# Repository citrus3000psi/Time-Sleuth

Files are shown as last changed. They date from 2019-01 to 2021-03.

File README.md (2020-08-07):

# Time Sleuth

A cheap and easy to build HDMI lag tester.  Through hole components were chosen to aid in assembly.  Resistors and Caps are still surface mount but a larger 0805 package size. 

An altera USB-Blaster is required to program the board. Firmware was created by Chriz2600 and can be found on his Github https://github.com/chriz2600/time-sleuth

For convenience the V1.1 PCB is shared on OSH Park.  Please order in 1.6mm thickness.
https://oshpark.com/shared_projects/Jw3gMtl8

A 3D printed case is also available but not required for the unit to function.  The STL file can be downloaded from here:
https://www.shapeways.com/product/DRHQ8MRWT/time-sleuth-top
https://www.shapeways.com/product/R2SNB5DNT/time-sleuth-bottom

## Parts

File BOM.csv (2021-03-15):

Reference | Quantity | Value | Footprint | Notes | DigiKey #
C2 C3 C23 | 3 | 10u | Capacitors_SMD:C_0805_HandSoldering | 16V
C10 C11 C12 C13 C14 C15 C16 C17 C18 C20 C22 C4 C5 C6 C7 C8 C9 | 17 | .1u | Capacitors_SMD:C_0805_HandSoldering | 50V
D1 | 1 | LED | LEDs:LED-5MM
J1 | 1 | 2000-1-1-20-00-BK | pads:HDMI_THRU |  | 1175-1700-ND
J2 | 1 | 548190519 | digikey-footprints:USB_Mini_B_Female_548190519 |  | WM17115-ND
J3 | 1 | AVR-JTAG-10 | Connect:IDC_Header_Straight_10pins |  | ED1543-ND
L1 | 1 | MH2029-100Y | Capacitors_SMD:C_0805_HandSoldering | 10 Ohm | MH2029-100YCT-ND
R1 | 1 | 300K | Resistors_SMD:R_0805_HandSoldering
R16 R8 R9 | 3 | 2.2K | Resistors_SMD:R_0805_HandSoldering
R2 | 1 | R_PHOTO | LEDs:LED-5MM |  | 475-1437-ND
R20 R5 | 2 | 1K | Resistors_SMD:R_0805_HandSoldering
R10 R11 R12 R13 R14 R15 R17 R18 R19 R21 R22 R3 R4 | 13 | 10K | Resistors_SMD:R_0805_HandSoldering
R6 | 1 | 510 | Resistors_SMD:R_0805_HandSoldering
R7 | 1 | 5K | Resistors_SMD:R_0805_HandSoldering
SW1 | 1 | SS-10-23NP-LE | pads:SS-10-23NP-LE |  | 563-1084-ND
SW1_OPT | 1 | SS-10-15SP-LE | pads:SS-10-23NP-LE |  | 563-1078-ND
U1 | 1 | 10M02SCE144C8G | Altera:altera144_wcenterpad |  | 544-3098-ND
U2 | 1 | TC1264-3.3VDBTR | TO_SOT_Packages_SMD:SOT-223-3Lead_TabPin2 |  | TC1264-3.3VDBCT-ND
U3 | 1 | TFP410PAP | Housings_QFP:TQFP-64_1EP_10x10mm_Pitch0.5mm |  | 296-12666-ND
X1 | 1 | CXO_DIP8 | Oscillators:Oscillator_DIP-8 | 27Mhz | 535-9194-5-ND

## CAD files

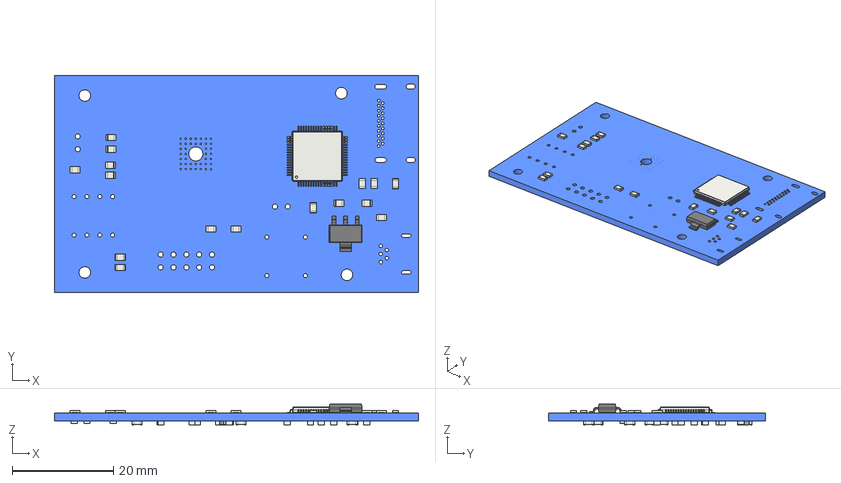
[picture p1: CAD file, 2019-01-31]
Kicad_ProjectV1.2/lag_tester2.FCStd
72.0 x 43.0 x 4.08 mm
Pcb
R_0805_
R_0805_001
R_0805_004
R_0805_005
R_0805_006
R_0805_007
R_0805_009
R_0805_010
R_0805_011
R_0805_012
R_0805_013
R_0805_014
R_0805_015
R_0805_016
SOT_223_
TQFP-64_10x10mm_Pitch0.5mm_
R_0805_017
R_0805_018
C_0805_
C_0805_001
R_0805_002
R_0805_003
C_0805_002
C_0805_003
C_0805_004
R_0805_008
C_0805_005
C_0805_006
C_0805_007
C_0805_008
C_0805_009
C_0805_010
C_0805_011
C_0805_012
C_0805_013
C_0805_014
C_0805_015
C_0805_016
C_0805_017
C_0805_018
C_0805_019
C_0805_020

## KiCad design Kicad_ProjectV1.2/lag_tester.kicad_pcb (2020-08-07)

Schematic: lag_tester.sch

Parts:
C2, C3, C23: 10u; C_0805_HandSoldering
C4, C5, C6, C7, C8, C9, C10, C11, C12, C13, C14, C15, C16, C17, C18, C20, C22: .1u; C_0805_HandSoldering
D1: LED; LED-5MM
J1: HDMI_A; HDMI_THRU
J2: USB_B_Mini; USB_Mini_B_Female_548190519
J3: AVR-JTAG-10; IDC_Header_Straight_10pins
L1: INDUCTOR; C_0805_HandSoldering
R1: 150; R_0805_HandSoldering
R2: R_PHOTO; LED-5MM
R3, R4, R10, R11, R12, R13, R14, R15, R17, R18, R19, R21, R22: 10K; R_0805_HandSoldering
R5: 1k; R_0805_HandSoldering
R6: 510; R_0805_HandSoldering
R7: 5K; R_0805_HandSoldering
R8, R9, R16: 2.2K; R_0805_HandSoldering
R20: 1K; R_0805_HandSoldering
SW1: SW_Coded; SS-10-23NP-LE
U1: 10M02SCE144I7G; altera144_wcenterpad
U2: TC1264-3.3VDBTR; SOT-223-3Lead_TabPin2
U3: TFP410PAP; TQFP-64_1EP_10x10mm_Pitch0.5mm
X1: CXO_DIP8; Oscillator_DIP-8

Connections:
/27CLK: U1.27, X1.5
/+3.3: C2.2, C4.2, C5.2, C6.2, C7.2, C8.2, C9.2, C10.2, C11.2, C12.2, C13.2, C14.2, C15.2, C16.2, J3.4, L1.1, R1.2, R9.1, R10.1, R12.1, R13.1, R15.1, R16.1, SW1.2, SW1.6, U1.1, U1.2, U1.12, U1.22, U1.29, U1.34, U1.35, U1.36, U1.37, U1.43, U1.56, U1.58, U1.64, U1.71, U1.72, U1.73, U1.82, U1.93, U1.102, U1.107, U1.108, U1.109, U1.111, U1.118, U1.121, U1.132, U1.136, U1.142, U1.144, U2.3, X1.1, X1.8
/+3.3_DVI: C17.2, C18.2, C20.2, C22.2, C23.2, L1.2, R6.1, R7.2, R8.2, U3.1, U3.3, U3.12, U3.18, U3.23, U3.29, U3.33
/+5: C3.2, J1.18, J2.5 (GND), R3.1, R4.1, U2.1
/+TMDS_0: J1.7, U3.25
/+TMDS_1: J1.4, U3.28
/+TMDS_2: J1.1, U3.31
/+TMDS_CLK: J1.10, U3.22
/-TMDS_0: J1.9, U3.24
/-TMDS_1: J1.6, U3.27
/-TMDS_2: J1.3, U3.30
/-TMDS_CLK: J1.12, U3.21
/A: R18.2, SW1.4, U1.4
/B: R17.1, SW1.3, U1.5
/C: R19.1, SW1.1, U1.6
/D: R21.1, SW1.8, U1.8
/D0: U1.46, U3.63
/D1: U1.47, U3.62
/D2: U1.48, U3.61
/D3: U1.49, U3.60
/D4: U1.50, U3.59
/D5: U1.51, U3.58
/D6: U1.52, U3.55
/D7: U1.53, U3.54
/D8: U1.54, U3.53
/D9: U1.59, U3.52
/D10: U1.60, U3.51
/D11: U1.61, U3.50
/D12: U1.62, U3.47
/D13: U1.63, U3.46
/D14: U1.65, U3.45
/D15: U1.67, U3.44
/D16: U1.68, U3.43
/D17: U1.69, U3.42
/D18: U1.70, U3.41
/D19: U1.74, U3.40
/D20: U1.75, U3.39
/D21: U1.76, U3.38
/D22: U1.78, U3.37
/D23: U1.79, U3.36
/DE: U1.44, U3.2
/DVI_CLK: U1.33, U3.57
/DVI_RST: R8.1, U1.40, U3.13
/E: R22.2, SW1.7, U1.9
/GND: C2.1, C3.1, C4.1, C5.1, C6.1, C7.1, C8.1, C9.1, C10.1, C11.1, C12.1, C13.1, C14.1, C15.1, C16.1, C17.1, C18.1, C20.1, C22.1, C23.1, J1.2, J1.5, J1.8, J1.11, J1.17, J1.SH, J2.1 (VBUS), J2.6 (Shield), J3.2, J3.10, R2.2, R11.1, R14.2, R17.2, R18.1, R19.2, R20.1, R21.2, R22.1, U1.11, U1.20, U1.30, U1.38, U1.45, U1.57, U1.66, U1.83, U1.96, U1.104, U1.110, U1.119, U1.133, U1.143, U1.145, U2.2, U3.10, U3.16, U3.17, U3.20, U3.26, U3.32, U3.34, U3.35, U3.48, U3.56, U3.64, U3.65, X1.4
/HPD: J1.19, R5.1
/HSYNC: U1.42, U3.4
/SCL: R16.2, U1.24, U3.15
/SDA: R9.2, U1.39, U3.14
/SENSOR: R1.1, R2.1, U1.7
/TCK: J3.1, R14.1, U1.16
/TDI: J3.9, U1.17
/TDO: J3.3, U1.18
/TMS: J3.5, U1.15
/VSYNC: U1.41, U3.5
unnamed: D1.1, R20.2
unnamed: D1.2, U1.115
unnamed: J1.15, R4.2
unnamed: J1.16, R3.2
unnamed: R5.2, U3.9
unnamed: R6.2, U3.19
unnamed: R7.1, U3.11
unnamed: R10.2, U1.122
unnamed: R11.2, U1.120
unnamed: R12.2, U1.131
unnamed: R13.2, U1.135
unnamed: R15.2, U1.13

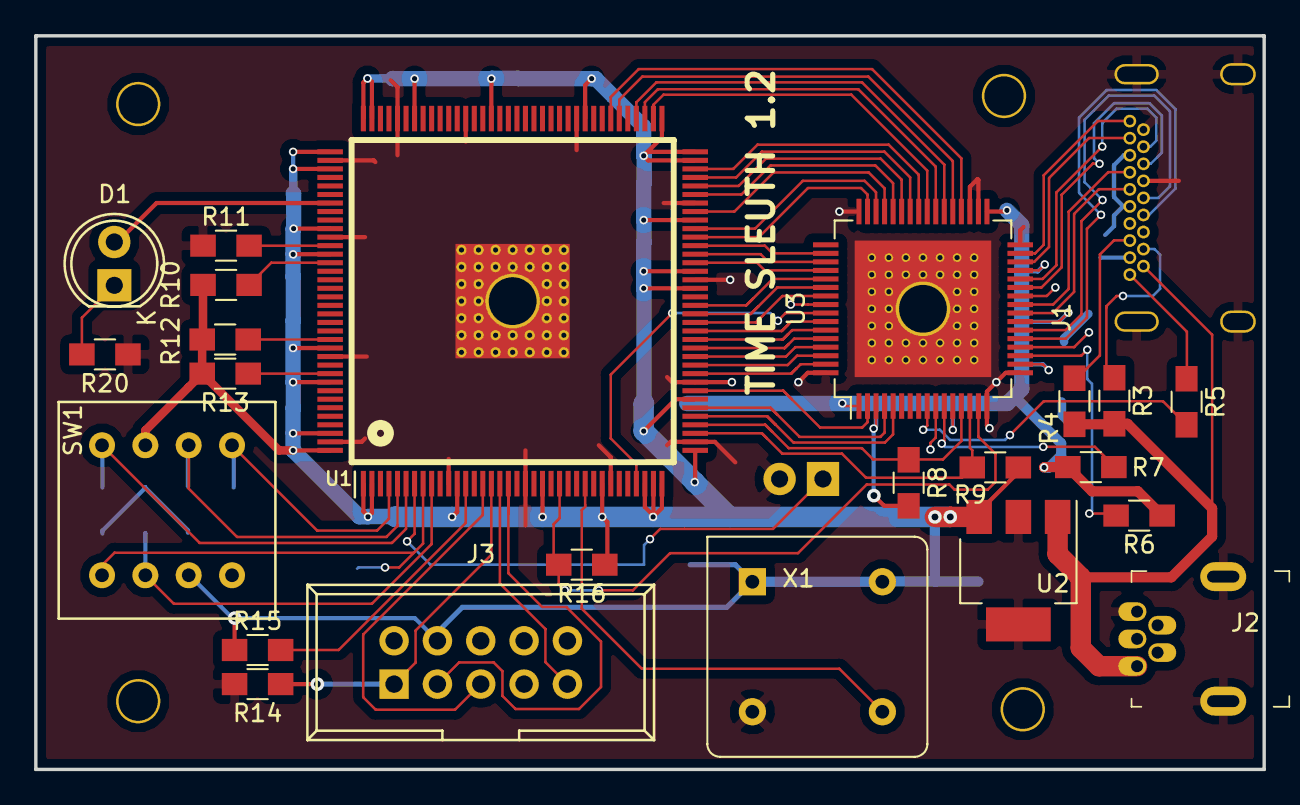
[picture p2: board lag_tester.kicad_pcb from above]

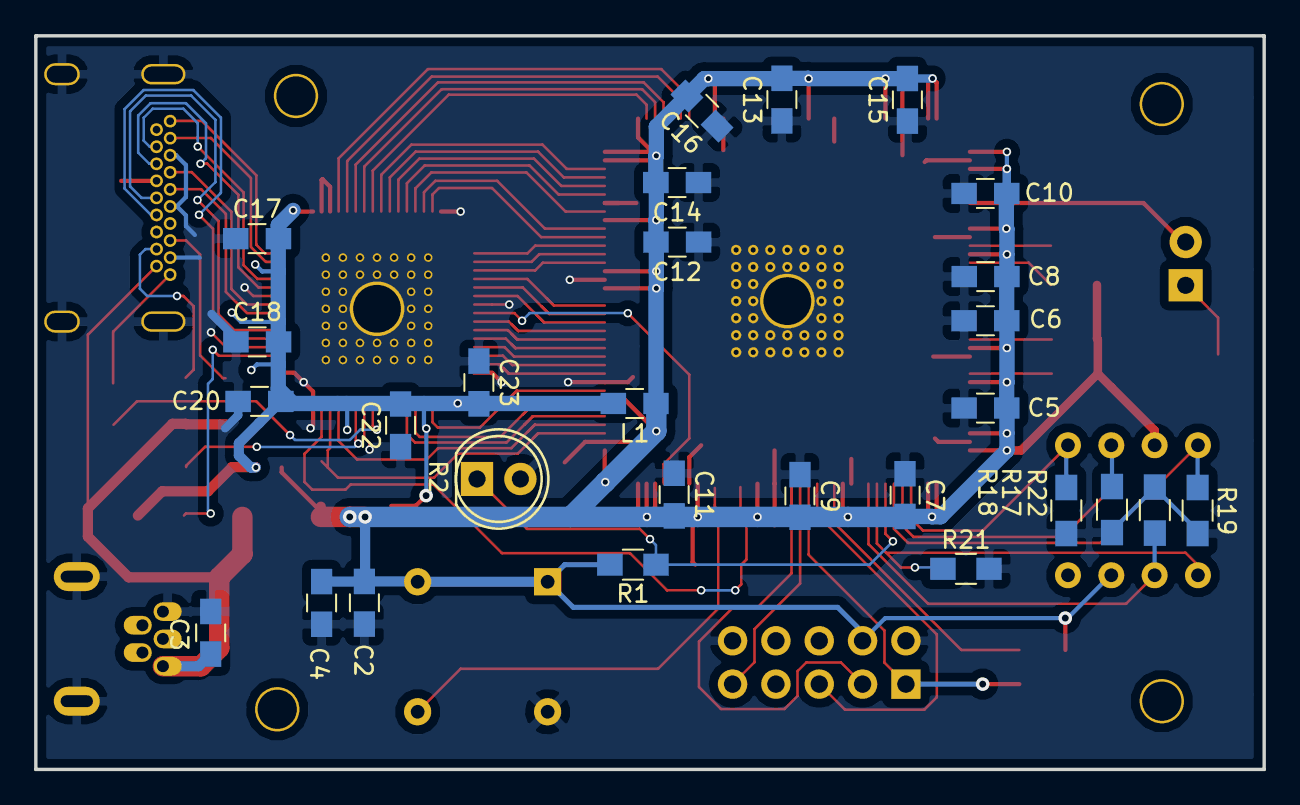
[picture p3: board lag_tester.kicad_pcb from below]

Board: 2 copper layers, 72.0 x 43.0 mm, 52 parts (28 on the bottom side), 67 nets.

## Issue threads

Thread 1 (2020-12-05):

1080p @ 240 Hz request

kynrek, 2020-12-05:
My monitor had a special TVR (turbo video response) mode that is only enabled with a 1080P 240hz signal, is it possible for the time sleuth to generate a signal at that frequency so I can check the response time?

Thanks,

coolrecep, 2023-03-17:
Yepp, any support for higher Hz?

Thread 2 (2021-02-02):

Can't download stl file for printing case

BitBlit88, 2021-02-02:
The link for downloading the stl file for 3D printing points to an external web site where I can't download any file.

bodgit, 2021-02-09:
If you sign in, you can download the .stl file.

BitBlit88, 2021-02-09:
I was signed in but there was no download button. But as I tried today the download button was visible. Perhaps it was a temporary issue on the web server.

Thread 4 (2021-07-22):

My tv isn't bright enough. Adjustments for photosensor?

toasterovenly, 2021-07-22:
Is it possible to adjust the sensitivity of the photosensor in code without having to modify any parts? I could probably reflash the firmware myself but i don't really know my way around kiCad. For the record my tv is just a normal LCD TV but the timesleuth doesn't detect the flashing at all when i hold it up to the screen.
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

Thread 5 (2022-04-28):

Feature request - Internal Battery

ZNahum, 2022-04-28:
With how unwieldy having a usb cord and an hdmi cord from this box is, please have the option to add an internal battery. From the form factor of the case, it would be great if we can add a single 18650 to power it.

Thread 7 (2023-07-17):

In circuit diagram is R1 value 150 in BOM is 300k

NuClear235, 2023-07-17:
In circuit diagram is R1 value 150 in BOM is 300k.
Is 300k the right value?

dangermousehouse, 2024-11-27:
Have just constructed one of these using R1 = 150 per the schematic - works as expected

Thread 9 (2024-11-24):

Shapeways marketplace = gone

dangermousehouse, 2024-11-24:
Sadly Shapeways has shut down  - a contract manufacturer has taken over the domain name and logo and shut down the marketplace.

Is there an alternative source for the shells please?

bodgit, 2025-03-17:
I realised I still had the files downloaded from when I printed them so I've re-uploaded them here: https://www.printables.com/model/1232708-time-sleuth-case

HTH

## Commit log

2019-01-31 Add Project Files
    [BOM.csv, lag_tester.kicad_pcb, lag_tester.sch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]
2020-08-07 Added 5 Position Switch
    [BOM.csv]
2020-08-07 Add V1.2 which has 5 position switch.
    [_saved_lag_tester.sch, lag_tester.kicad_pcb, lag_tester.sch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]
2021-03-12 Fix up BOM
    * Correct capacitor quantities; there's one more 10uF and one fewer
    0.1uF
    * Fold both separate 1K resistors into one line item
    * Add the missing R21 and R22 resistors and update the quantity
    [BOM.csv]
